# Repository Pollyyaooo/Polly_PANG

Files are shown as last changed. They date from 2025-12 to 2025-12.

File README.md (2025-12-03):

# **PANG! — A Reaction-Based Handheld Game**

## **1. Overview**

**PANG!** is a fast-paced reaction game inspired by 90s handheld toys such as **Bop It**.  
The name **“PANG!”** comes from the sharp popping sound that represents a sudden, reflex-driven moment—just like the quick actions players must perform in the game.

Players choose from three difficulty levels and must respond to directional commands—**up, down, left, right**—within a strict time limit. Each successful action advances the game to the next level, while a missed or incorrect move ends the run instantly.

The game is powered by a **Xiao ESP32-C3**, using a combination of motion sensing, manual input, LED animations, buzzer audio cues, and an OLED display. A LiPo battery and custom 3D-printed enclosure make the device fully portable.

---

## **2. How the Game Works**

### **1. Game Preparation**
- Upon powering on, the NeoPixel LEDs play a playful startup animation accompanied by a buzzer jingle and a white breathing-light effect.
- The ADXL345 accelerometer performs **initial calibration**.

---

### **2. Gameplay Loop**

#### **Actions and Timing**
- The player uses the **rotary encoder** to select a difficulty mode:  
  **Easy / Normal / Hard** — each determines the allowed reaction time.
- Each mode has 10 levels.
- Each level generates a sequence of actions:  
`Actions per level = Level × 2 + 2`
- Pressing the encoder button begins the game.
- Players must perform each action within a **reaction time** based on the chosen difficulty:  
  - Easy: 5 s  
  - Normal: 3 s  
  - Hard: 1.5 s

#### **Scoring System**
- Each level has a **level score**:
`Level score = Level × 10 × Difficulty multiplier`
- **Difficulty multiplier:**  
  - Easy ×1  
  - Normal ×2  
  - Hard ×3
- **Per-action score**:
`Per-action score = Level score ÷ Number of actions in that level`
- **Total score** accumulates across all correctly completed actions.  
- **Partial completion:** If the player fails an action (wrong direction or time exceeded), the current level ends immediately, but points for correctly performed actions before the mistake are retained.

#### **High Score System**
The game includes a simple **three-slot leaderboard**.  
If the player achieves a score high enough to enter the ranking, they may use the rotary encoder to choose **three letters** to save their name.

---

### **3. Game Over**
A run ends when:
- The player performs the **wrong move**, or  
- The correct accelerometer thresholds are **not met within the time limit**

On failure:
- LEDs flash a **yellow double-jump pattern**
- Buzzer plays a short “failure tone”
- OLED displays **GAME OVER**

The player can restart from the difficulty menu without power cycling.

---

### **4. Game Win**
If all 10 levels are completed:
- NeoPixel ring shows a **rainbow animation**
- Buzzer plays a celebratory melody
- OLED displays **YOU WIN!**

Player then returns to the difficulty selection screen.

---

## **3. Hardware Components**

### **Microcontroller**
- **Seeed Studio Xiao ESP32-C3**

### **Sensors & Inputs**
- **ADXL345 Accelerometer**  
- **Rotary Encoder**

### **Outputs**
- **SSD1306 128×64 OLED Display**  
- **NeoPixel LED Ring (27 pixels)**  
- **Piezo Buzzer**

### **Power System**
- **3.7V LiPo Battery**  
- **Inline On/Off Switch**

---

## **4. Enclosure Design Thought Process**

The enclosure design went through two iterations: a racket-inspired prototype and the final cylindrical handheld. Below are the details for each version.

### **1.0 Racket Version**
- **Concept:** ping-pong paddle shape, inspired by fast reaction movements.  
- **Issues encountered:**  
  - **Too thin** to reliably house OLED, accelerometer, rotary encoder, switch, and wiring.  
  - Increasing thickness led to structural fragility and **broken jumper wires**.  
  - Swinging the paddle created **complex 3D motion** that produced inconsistent accelerometer readings.  
- **Decision:** abandoned due to manufacturability and sensing reliability concerns.  

<p align="center">
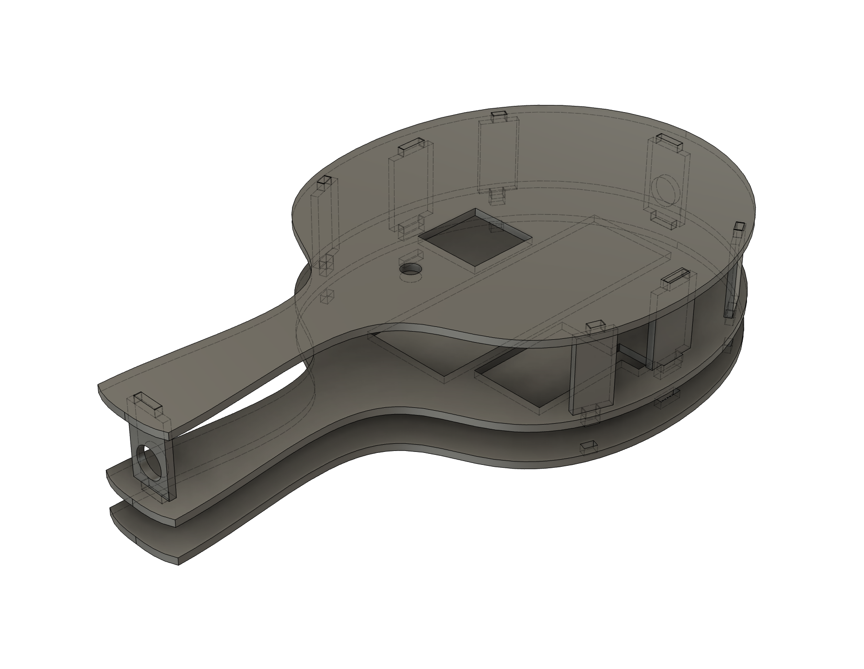
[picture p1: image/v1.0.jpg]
  
</p>

---

### **2.0 Cylindrical Version**
- **Concept:** compact cylindrical handheld shell optimized for robustness and consistent motion sensing.  
- **Advantages:**  
  - **Larger internal volume** for tidy wiring and secure component placement.  
  - **Thicker walls** reduce risk of broken jumpers and improve durability.  
  - **Stable single-hand grip** yields more consistent accelerometer data for gameplay.  
  - **Front face layout:** OLED, rotary encoder, switch, and buzzer placed for intuitive interaction.  
  - **Side-mounted NeoPixel ring** with a narrow slit allows the LEDs to glow outward without blocking controls.  
- **Result:** chosen as the final enclosure for its balance of usability, reliability, and manufacturability.  

<p align="center">
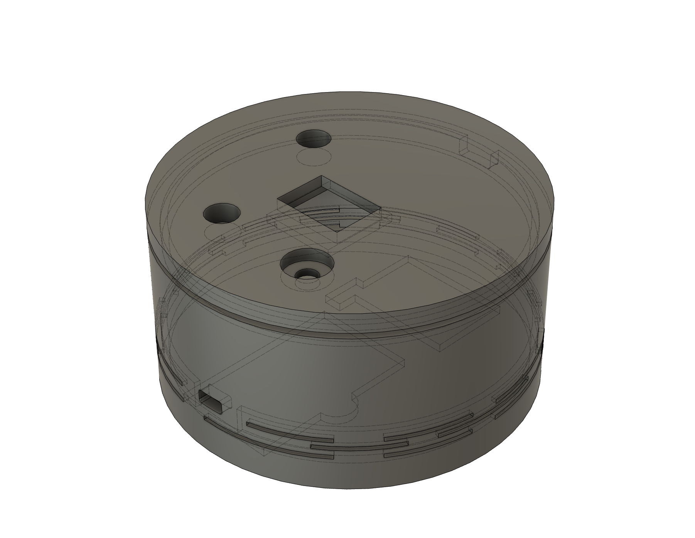
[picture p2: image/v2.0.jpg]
  
</p>

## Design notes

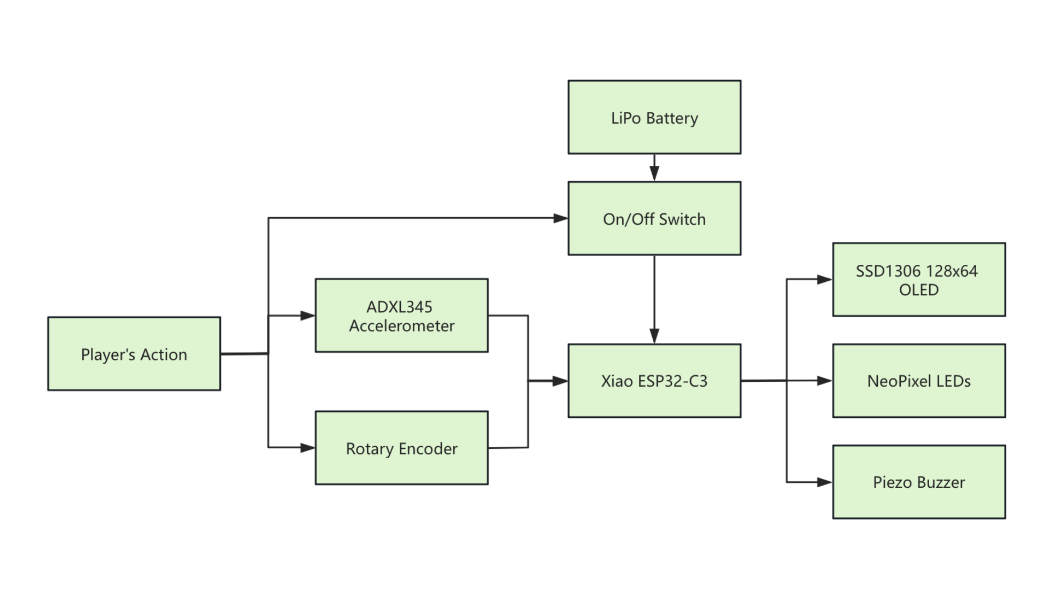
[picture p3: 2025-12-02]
Documentation/PANG_System Diagram.jpg

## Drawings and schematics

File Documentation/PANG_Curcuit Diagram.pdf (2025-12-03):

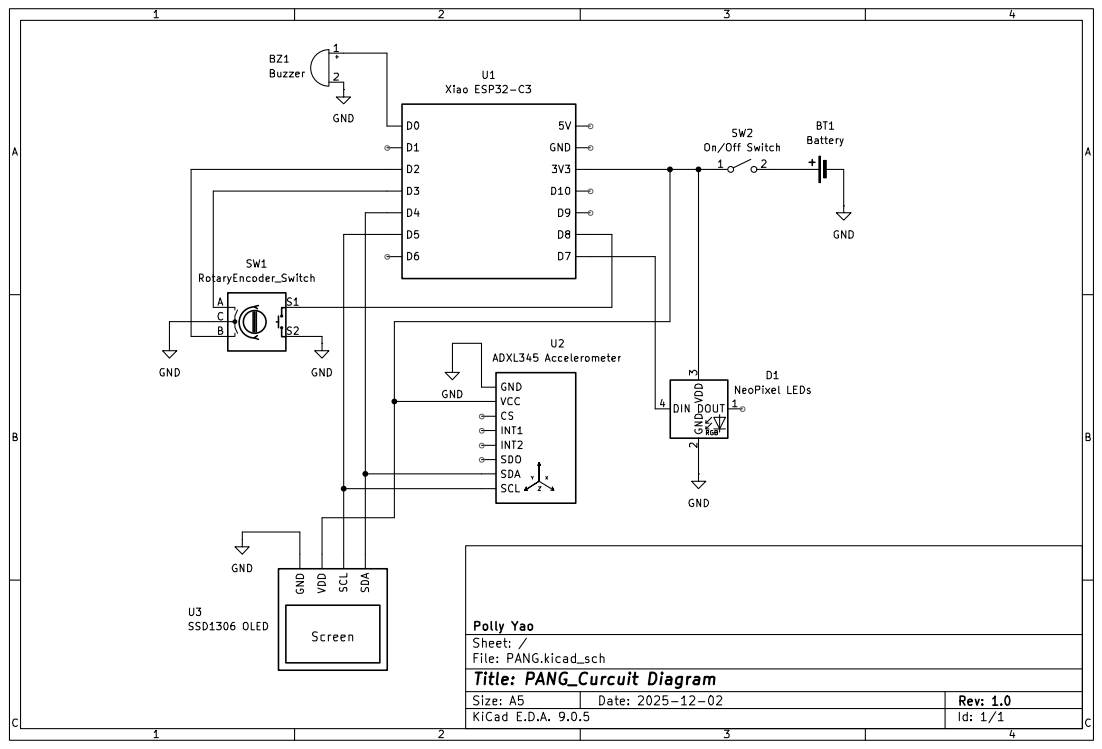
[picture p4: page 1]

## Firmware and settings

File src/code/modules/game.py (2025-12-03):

# game.py
import time
import random
from adafruit_display_text import label
import terminalio
from modules.buzzer_start import buzzer_start
from modules.buzzer_over import buzzer_over
from modules.buzzer_win import buzzer_win
from modules.highscore import load_scores, save_scores, check_new_highscore, insert_new_score, show_highscores
from modules.initials_input import enter_initials
from modules import led_game_over
from modules import led_game_win

# ========== action name ==========
ACTIONS = ["UP", "DOWN", "LEFT", "RIGHT"]
ACTION_DISPLAY = {"UP": "UP", "DOWN": "DOWN", "LEFT": "LEFT", "RIGHT": "RIGHT"}

# ========== choose difficulty ==========
DIFFICULTY_MULTIPLIER = {"Easy": 1, "Normal": 2, "Hard": 3}
DIFFICULTY_REACTION_TIME = {"Easy": 5.0, "Normal": 3.0, "Hard": 1.5}

# ========== counter ==========
ACTION_COUNTER = {"UP": 0, "DOWN": 0, "LEFT": 0, "RIGHT": 0}

# ========== filter ==========
def low_pass_filter(prev, curr, alpha=0.5):
    return alpha * curr + (1 - alpha) * prev

# ======= motion detect =======

MOTION_IDLE = 0       # 静止阶段
MOTION_ACTION = 1     # 动作峰值阶段
MOTION_RESET = 2      # 回正阶段（忽略所有动作）

motion_state = MOTION_IDLE
last_action = None


def detect_action(accel, baseline,
                  th_y=1.0, th_z=1.0,
                  reset_th=0.4):
   
    global motion_state, last_action

    x, y, z = accel
    bx, by, bz = baseline
    dy = y - by
    dz = z - bz

    # ====== Still ======
    if motion_state == MOTION_IDLE:
        # right
        if dy < -th_y:
            motion_state = MOTION_ACTION
            last_action = "RIGHT"
        # left
        elif dy > th_y:
            motion_state = MOTION_ACTION
            last_action = "LEFT"
        # up
        elif dz > th_z:
            motion_state = MOTION_ACTION
            last_action = "UP"
        # down
        elif dz < -th_z:
            motion_state = MOTION_ACTION
            last_action = "DOWN"
        else:
            return None
        return None  # just start

    # ====== motion biggest =====
    elif motion_state == MOTION_ACTION:
        # leave and back
        if abs(dy) < reset_th and abs(dz) < reset_th:
            motion_state = MOTION_RESET
        return None

    # ====== motion back ======
    elif motion_state == MOTION_RESET:
        # ddefault position
        if abs(dy) < reset_th and abs(dz) < reset_th:
            action = last_action
            motion_state = MOTION_IDLE
            last_action = None
            return action

        return None

# ========== show text ==========
def show_text(display, main_group, text, y_offset=0):
    while len(main_group) > 0:
        main_group.pop()
    txt = label.Label(
        terminalio.FONT,
        text=text,
        color=0xFFFFFF,
        x=0,
        y=(display.height // 2 - 4) + y_offset
    )
    main_group.append(txt)
    display.refresh()

# ========== main loop ==========
def play_game(display, main_group, accelerometer, baseline, button, encoder, pixels):
    
    while True:
        # ==================== ddifficulty ====================
        options = ["Easy", "Normal", "Hard"]
        index = 0
        last_position = encoder.position

        def display_difficulty(text):
            while len(main_group) > 0:
                main_group.pop()
            txt_label = label.Label(
                terminalio.FONT,
                text=text,
                color=0xFFFFFF,
                x=0,
                y=display.height // 2 - 4
            )
            main_group.append(txt_label)
            display.refresh()

        display_difficulty(f"Select difficulty:\n{options[index]}")

        while True:
            position = encoder.position
            if position != last_position:
                if position > last_position:
                    index = (index + 1) % len(options)
                else:
                    index = (index - 1) % len(options)
                display_difficulty(f"Select difficulty:\n{options[index]}")
                last_position = position
                time.sleep(0.05)

            if not button.value:
                time.sleep(0.2)
                if not button.value:
                    difficulty_level = options[index]
                    break

        multiplier = DIFFICULTY_MULTIPLIER[difficulty_level]
        reaction_time = DIFFICULTY_REACTION_TIME[difficulty_level]

        # ==================== game start ====================
        score = 0
        show_text(display, main_group, "Game Start")
        buzzer_start()
        time.sleep(1)

        prev_x, prev_y, prev_z = baseline
        game_cleared = True

        for level in range(1, 11):
            actions_count = level * 2 + 2
            level_score = level * 10 * multiplier
            per_action_score = level_score // actions_count

            sequence = [random.choice(ACTIONS) for _ in range(actions_count)]
            show_text(display, main_group, f"LEVEL {level}\nScore {score}")
            time.sleep(0.8)

            for expected in sequence:
                show_text(display, main_group, f"LEVEL {level}\n{ACTION_DISPLAY[expected]}")
                start_t = time.monotonic()
                detected = None

                while time.monotonic() - start_t < reaction_time:
                    x, y, z = accelerometer.acceleration
                    prev_x = low_pass_filter(prev_x, x)
                    prev_y = low_pass_filter(prev_y, y)
                    prev_z = low_pass_filter(prev_z, z)

                    detected = detect_action((prev_x, prev_y, prev_z), baseline)

                    # ==== wrong ====
                    if detected is not None and detected != expected:
                        show_text(display, main_group, "WRONG!")
                        time.sleep(0.6)
                        detected = None
                        break

                    # ==== correct ====
                    if detected == expected:
                        score += per_action_score
                        time.sleep(0.25)  # 冷却，避免回手误判
                        break

                    time.sleep(0.02)

 
                if detected != expected:
                    show_text(display, main_group, "GAME OVER")
                    buzzer_over()
                    led_game_over.show(pixels)
                    time.sleep(1.5)
                    game_cleared = False
                    break
            else:
                show_text(display, main_group, f"Level {level} OK!\nScore:{score}")
                time.sleep(1.0)
                continue

            break 

        # ==================== win ====================
        if game_cleared:
            show_text(display, main_group, "YOU WIN!")
            buzzer_win()
            led_game_win.show(pixels)
            time.sleep(2)
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

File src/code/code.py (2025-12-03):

import time
import board
import busio
import displayio
import i2cdisplaybus
import digitalio
import rotaryio
import neopixel
import adafruit_adxl34x
import adafruit_displayio_ssd1306


from modules import ball_bounce, buzzer_open, led_game_open, calibration, game

# ========== NeoPixel ==========
NUM_PIXELS = 22
pixels = neopixel.NeoPixel(board.D7, NUM_PIXELS, auto_write=False)

# ========== OLED ==========
displayio.release_displays()
i2c = busio.I2C(board.SCL, board.SDA)
display_bus = i2cdisplaybus.I2CDisplayBus(i2c, device_address=0x3C)
display = adafruit_displayio_ssd1306.SSD1306(display_bus, width=128, height=64)
main_group = displayio.Group()
display.root_group = main_group

start_time = time.monotonic()

# ========== button ==========
button = digitalio.DigitalInOut(board.D8)
button.direction = digitalio.Direction.INPUT
button.pull = digitalio.Pull.UP

# ========== Rotary Encoder ==========
encoder = rotaryio.IncrementalEncoder(board.D3, board.D2)  # clk=D3, dt=D2

# ========== accelerometer ==========
accelerometer = adafruit_adxl34x.ADXL345(i2c)

# ========== open ==========
tones = [(440, 0.12), (660, 0.12), (880, 0.12)]
for freq, dur in tones:
    buzzer_open.play_tone(freq, dur, pin=board.D1)
    end_t = time.monotonic() + dur
    while time.monotonic() < end_t:
        led_game_open.breathing_step(pixels, start_time)
        time.sleep(0.005)
    time.sleep(0.03)

animation = ball_bounce.ball_bounce(display, main_group)
for _ in animation:
    led_game_open.breathing_step(pixels, start_time)
    time.sleep(0.005)
led_game_open.turn_off(pixels)

# ========== baseline ==========
baseline_x, baseline_y, baseline_z = calibration.zero_offset_calibration(
    i2c=i2c,
    button=button,
    display=display,
    main_group=main_group
)
print("Baseline:", baseline_x, baseline_y, baseline_z)

# ========== loop ==========
game.play_game(
    display=display,
    main_group=main_group,
    accelerometer=accelerometer,
    baseline=(baseline_x, baseline_y, baseline_z),
    button=button,
    encoder=encoder,
    pixels=pixels
)
